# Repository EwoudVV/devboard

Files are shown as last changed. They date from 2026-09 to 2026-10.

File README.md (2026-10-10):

# Devboard

A small STM32 devboard for deving

## details
- Compatible with a breadboard
- USB-C programming port
- SD card holder
- 32 header pins total: 22 GPIO, including 9 analog inputs, plus debug and power pins
- STM32 MCU
- 4 layer board
- 24x44mm board size
- 2 side component assembly

## images
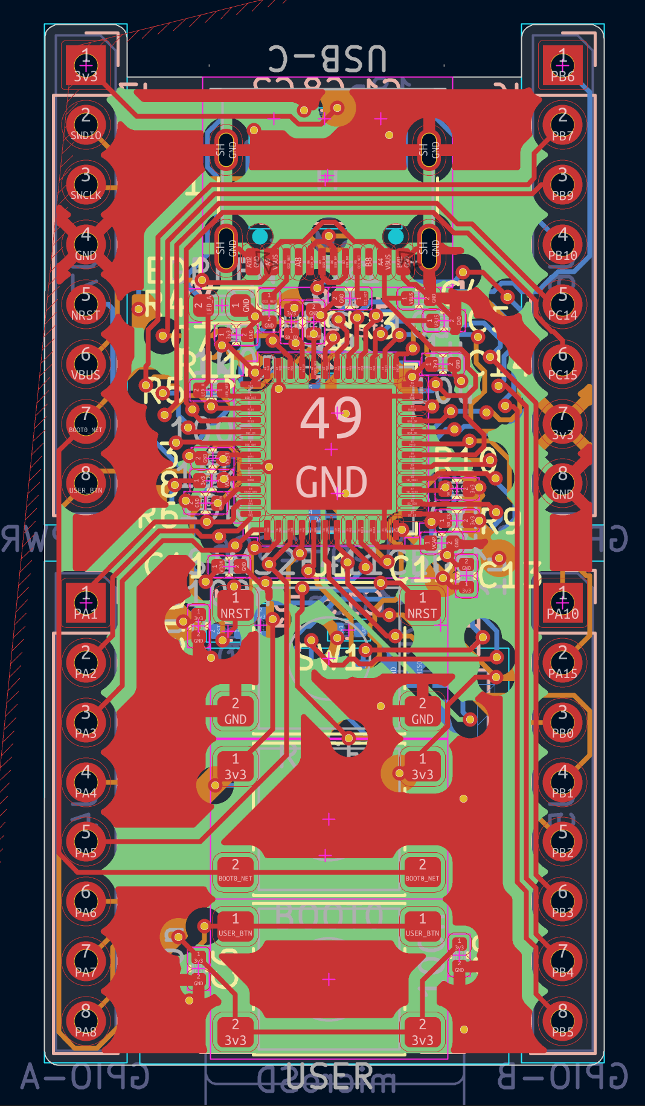
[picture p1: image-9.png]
The board in PCB editor: 
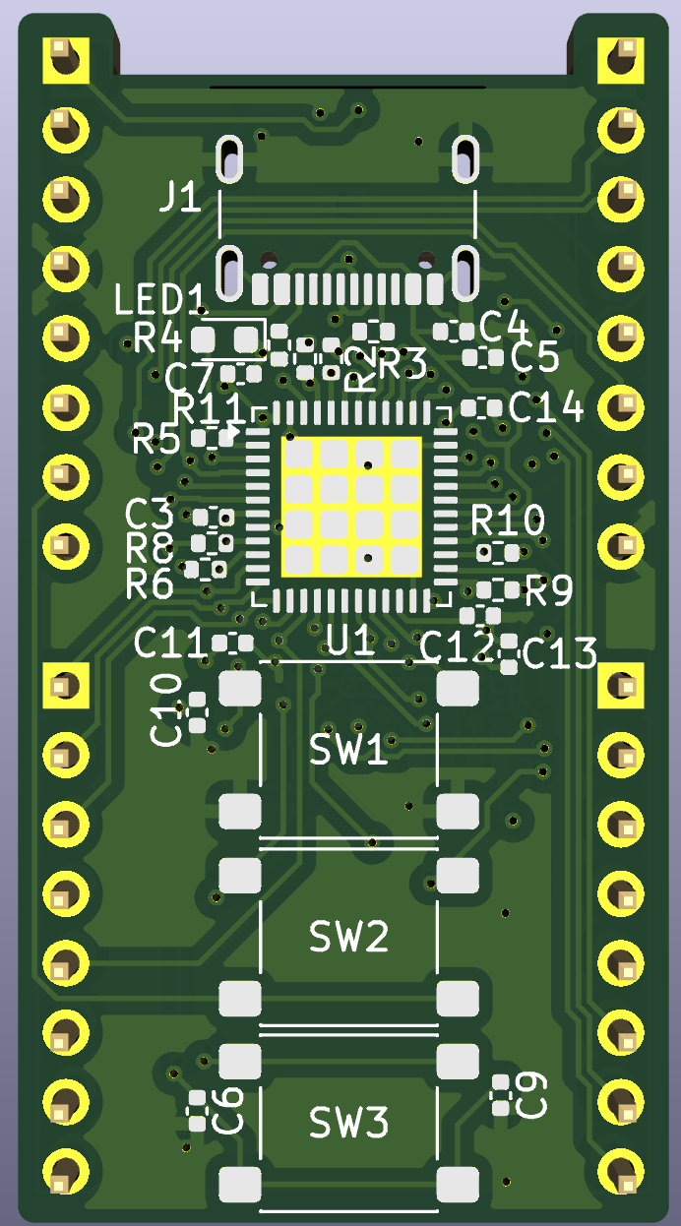
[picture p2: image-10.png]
The board in 3d viewer: 

## goal
- Purpose: a functional and useful devboard
- MCU: STM32 (MCU_ST_STM32F4:STM32F411CEUx)
- Features: USB-C + UART, SD card, expanded GPIO
- Size: as small as possible

## status

project finished!!
Once I get funding, I will order 10 assembled PCBs from PCBway.

## bom

Parts from the [PCBWay BOM](production/pcbway_bom.xlsx), with quantities for one board. The [KiCad CSV export](production/bom.csv) is also available.

| Reference | Qty | Manufacturer | Part number | Package |
| --- | ---: | --- | --- | --- |
| C1, C2 | 2 | Murata | GRM1555C1H180JA01D | 0402 |
| C3, C6, C7, C8, C9, C11, C15 | 7 | Samsung | CL05B104KB5NNNC | 0402 |
| C5, C13 | 2 | Samsung | CL05A105KO5NNNC | 0402 |
| C4, C14 | 2 | Samsung | CL05A106KP5NNNC | 0402 |
| C10 | 1 | Murata | GRM155R61A475MEAA | 0402 |
| C12 | 1 | Murata | GRM155R61A225KE95D | 0402 |
| R3, R4 | 2 | Yageo | RC0402FR-075K1L | 0402 |
| R9, R10, R11, R12, R13 | 5 | Yageo | RC0402FR-0747KL | 0402 |
| R8 | 1 | Yageo | RC0402FR-0710RL | 0402 |
| R1, R2, R6 | 3 | Yageo | RC0402FR-0710KL | 0402 |
| R5 | 1 | Yageo | RC0402FR-071KL | 0402 |
| U1 | 1 | STMicroelectronics | STM32F411CEU6 | QFN-48 7x7 |
| U2 | 1 | Diodes Incorporated | AP2112K-3.3TRG1 | SOT-23-5 |
| D1 | 1 | STMicroelectronics | USBLC6-2SC6 | SOT-23-6 |
| LED1 | 1 | Lite-On | LTST-C190GKT | 0603 |
| Y1 | 1 | Abracon | ABM3-25.000MHZ-D2Y-T | 5.0x3.2mm |
| J1 | 1 | GCT | USB4105-GF-A | USB-C 16P |
| J2 | 1 | Hirose | DM3AT-SF-PEJM5 | microSD |
| SW1, SW2, SW3 | 3 | C&K | PTS645SM43SMTR92 LFS | 6x6mm SMD |

The four through-hole headers are soldered separately and are not included in this BOM. For J1, check the USB4105 pin-length variant against the footprint, as noted in the PCBWay BOM.

## repo structure
- `devboard.kicad_pro` / `.kicad_sch` / `.kicad_pcb`: KiCad project (root)
- `journal.md`: devlog journals
- `README.md`: this file
- `production`: production files, like gerbers, bom, cpl
- `docs/pinout.md`: header pinout and on-board connections
- `firmware`: starter LED, button, and USB serial firmware

## getting started

[Pinout and connections](docs/pinout.md)

[Building and flashing the starter firmware](firmware/README.md)

Designed by EVV
Made for Hack Club Half Life
9/16/26

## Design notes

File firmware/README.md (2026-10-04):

# Starter firmware

Blinks the green LED on PC13, reports the USER button on PA0, and gives the board a USB serial port. The SD card pins are left alone.

Compiled for STM32F411CEU6 with 512 KB flash and 128 KB RAM. It uses the board's 25 MHz crystal to run the CPU at 96 MHz and USB at 48 MHz. The button is active high and debounced for 25 ms. The LED is active high and changes state every 500 ms.

This builds, but I haven't tested it on a physical board yet.

## Build

Install a complete [Arm GNU embedded toolchain](https://developer.arm.com/tools-and-software/gnu-toolchain), including its C library. A compiler-only package without `stdint.h`, `nano.specs`, and the embedded libraries is not enough.

From this folder:

```sh
sh setup.sh
make
make test
```

If the toolchain is not on PATH:

```sh
make PREFIX=/path/to/toolchain/bin/arm-none-eabi-
```

Outputs are `build/devboard.elf`, `build/devboard.bin`, and `build/devboard.hex`. The BIN and HEX from the checked build are also in `releases/`.

`setup.sh` downloads libopencm3 from its upstream repository and checks out the revision in `libopencm3.version`. The library is LGPL-3.0-or-later; its license is included in `LIBRARY-LICENSE.txt`. The local download and build folders are ignored by Git.

## Flash over SWD

Power the board through USB-C. Connect the probe's ground to J7.4, SWDIO to J7.2, and SWCLK to J7.3. If the probe has a target voltage sense input, connect it to J7.1. NRST is available on J7.5. Check your probe's pin labels before connecting it.

With an ST-Link and OpenOCD installed:

```sh
make flash
```

The command programs the ELF, verifies it, and resets the board. It does not require a separately installed bootloader. For this application, release BOOT0 before resetting.

## USB serial

Use a USB data cable. After flashing and resetting, open the new USB serial device at 115200 baud. On macOS it should appear as `/dev/cu.usbmodem*`; Linux normally uses `/dev/ttyACM*`. The baud value is accepted for terminal compatibility; USB carries the data directly.

The terminal should show:

```text
devboard ready
Type help for commands.
```

Send a command followed by Enter:

| Command | Result |
| --- | --- |
| `help` | Lists the commands |
| `status` | Uptime, button state, press count, LED state, blink mode, and dropped-message count |
| `led on` | Stops blinking and turns the LED on |
| `led off` | Stops blinking and turns the LED off |
| `blink` | Resumes blinking |

Pressing USER prints `button pressed`; releasing it prints `button released`. RESET restarts the application and may reconnect the serial port. The terminal needs to assert DTR, which normal serial terminals do when opening the port.

USB output is buffered without waiting for a host. The LED and button keep running when the terminal is closed. If a connected host stops reading long enough to fill the buffer, the message is dropped rather than blocking the application; `status` includes the drop count.

The USB descriptor uses the development CDC identifiers `0483:5740`. Use assigned identifiers for a distributed product. The serial string is currently `DEVBOARD-001`, for the first test board.

## First board checks

1. Before connecting USB, check for a short between 3.3 V and GND.
2. Power it and measure the 3.3 V rail.
3. Flash over SWD and verify that PC13's LED blinks.
4. Open USB serial, send `status`, and try the LED commands.
5. Press and release USER. Confirm one event per action and a rising press count.
6. Reset, then disconnect and reconnect USB. Check that serial comes back and the LED still runs.

The host test checks button bounce, a held press, release, and the millisecond counter wrapping. It does not test USB enumeration or physical hardware.

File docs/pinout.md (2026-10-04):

# Devboard pinout

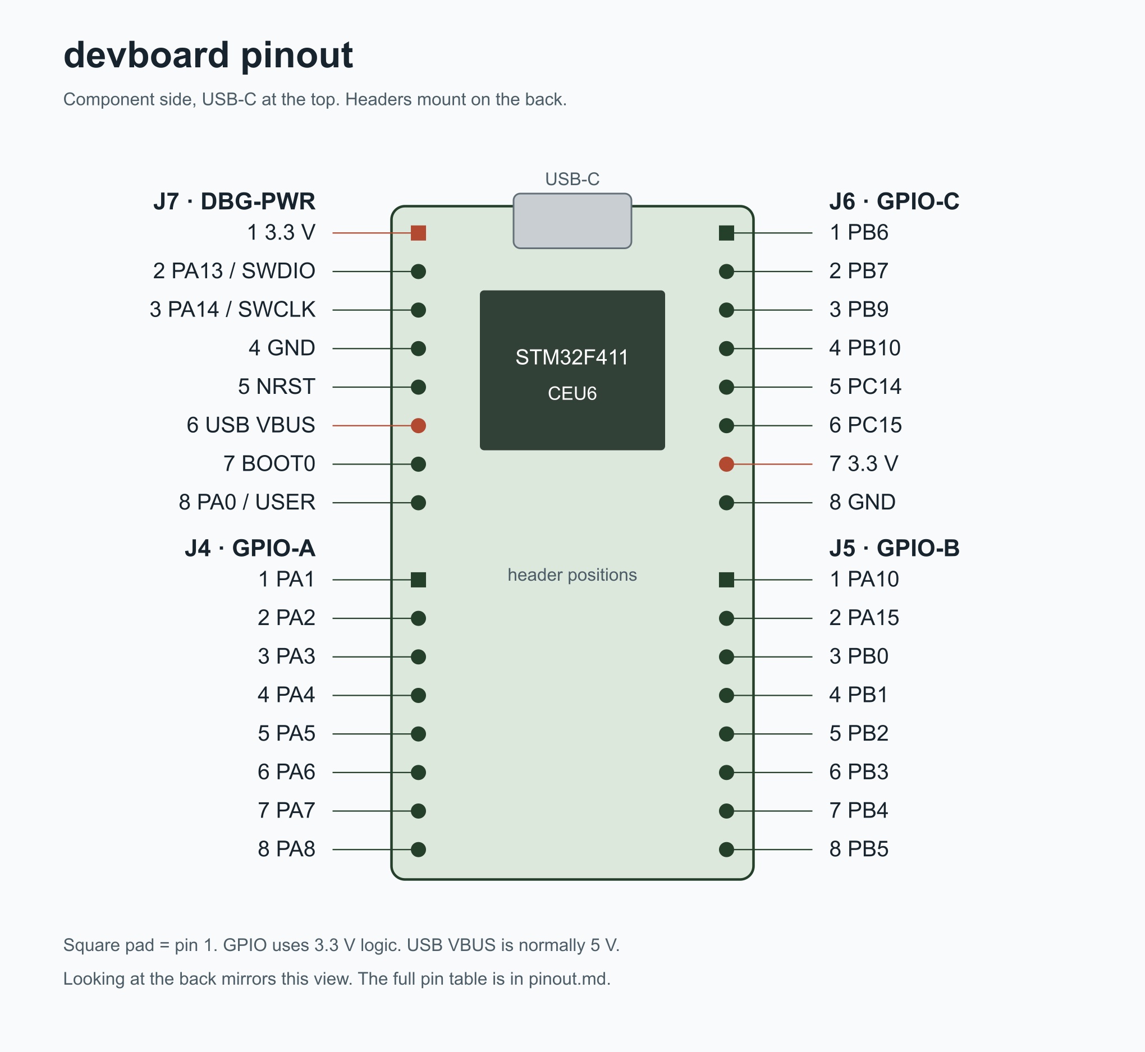
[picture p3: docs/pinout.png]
Devboard pinout


View from the component side, with USB-C at the top. The headers are mounted on the back. Pin 1 is the square pad. Looking at the back mirrors the positions in this diagram.

The four headers have 32 pins total. J4, J5, and J6 expose 22 GPIO pins, including nine ADC inputs. J7 carries power, programming, reset, boot, and the user button.

| Pin | J7: upper left | J6: upper right | J4: lower left | J5: lower right |
| --- | --- | --- | --- | --- |
| 1 | 3.3 V | PB6 | PA1 / ADC1_IN1 | PA10 |
| 2 | PA13 / SWDIO | PB7 | PA2 / ADC1_IN2 | PA15 |
| 3 | PA14 / SWCLK | PB9 | PA3 / ADC1_IN3 | PB0 / ADC1_IN8 |
| 4 | GND | PB10 | PA4 / ADC1_IN4 | PB1 / ADC1_IN9 |
| 5 | NRST | PC14 | PA5 / ADC1_IN5 | PB2 |
| 6 | USB VBUS | PC15 | PA6 / ADC1_IN6 | PB3 |
| 7 | BOOT0 | 3.3 V | PA7 / ADC1_IN7 | PB4 |
| 8 | PA0 / USER | GND | PA8 | PB5 |

GPIO and ADC signals use 3.3 V logic. Keep analog inputs between GND and 3.3 V. USB VBUS is the USB supply, normally 5 V; it is not a GPIO pin. Power the first board from USB-C rather than driving the 3.3 V rail from another supply.

## On-board connections

| Function | MCU pin | Notes |
| --- | --- | --- |
| Green LED | PC13 | Active high, through R5 (1 kΩ) to the LED; LED cathode goes to GND |
| USER button | PA0 | Active high, external 10 kΩ pulldown; also on J7.8 |
| RESET button | NRST | Pulls reset low; also on J7.5 |
| BOOT0 button | BOOT0 | Pulls BOOT0 high; also on J7.7 |
| USB D− | PA11 | USB OTG FS, AF10 |
| USB D+ | PA12 | USB OTG FS, AF10 |
| USB VBUS sense | PA9 | Connected to USB VBUS |
| SWD data | PA13 | J7.2 |
| SWD clock | PA14 | J7.3 |
| Main crystal | PH0 / PH1 | 25 MHz |
| SD chip select | PB12 | Active low |
| SD clock | PB13 | SPI2, AF5 |
| SD MISO | PB14 | SPI2, AF5 |
| SD MOSI | PB15 | SPI2, AF5 |
| SD card detect | PB8 | Pulled up; check the socket switch behavior on the first board |

The SD slot is wired for SPI, not four-bit SDIO. Its DAT1 and DAT2 pins have pullups but are not connected to MCU data pins. PA0 and PC13 are occupied by the button and LED. PA9, PA11, and PA12 are occupied by USB. Keep PA13 and PA14 for SWD while debugging.

PA15, PB3, and PB4 have debug alternate functions after reset. If you use them as GPIO, configure them explicitly and keep SWD on PA13/PA14. PC14 and PC15 are low-speed oscillator pins that can be GPIO while the LSE oscillator is disabled.

Pin assignments were checked against both the schematic netlist and PCB pads. MCU alternate functions and ADC channels are listed in the [STM32F411 datasheet](https://www.st.com/resource/en/datasheet/stm32f411cc.pdf).

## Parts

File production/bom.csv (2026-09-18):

Refs | Value | Footprint | Qty | DNP
C1 | 18p | Capacitor_SMD:C_0402_1005Metric | 1
C2 | 18p | Capacitor_SMD:C_0402_1005Metric | 1
C3 | 100n | Capacitor_SMD:C_0402_1005Metric | 1
C4 | 10u | Capacitor_SMD:C_0402_1005Metric | 1
C5 | 1u | Capacitor_SMD:C_0402_1005Metric | 1
C6 | 100n | Capacitor_SMD:C_0402_1005Metric | 1
C7 | 100n | Capacitor_SMD:C_0402_1005Metric | 1
C8 | 100n | Capacitor_SMD:C_0402_1005Metric | 1
C9 | 100n | Capacitor_SMD:C_0402_1005Metric | 1
C10 | 4u7 | Capacitor_SMD:C_0402_1005Metric | 1
C11 | 100n | Capacitor_SMD:C_0402_1005Metric | 1
C12 | 2u2 | Capacitor_SMD:C_0402_1005Metric | 1
C13 | 1u | Capacitor_SMD:C_0402_1005Metric | 1
C14 | 10u | Capacitor_SMD:C_0402_1005Metric | 1
C15 | 100n | Capacitor_SMD:C_0402_1005Metric | 1
D1 | USBLC6-2SC6 | Package_TO_SOT_SMD:SOT-23-6 | 1
J1 | USB-C | Connector_USB:USB_C_Receptacle_GCT_USB4105-xx-A_16P_TopMnt_Horizontal | 1
J2 | microSD | Connector_Card:microSD_HC_Hirose_DM3AT-SF-PEJM5 | 1
LED1 | GREEN | LED_SMD:LED_0603_1608Metric | 1
P1 | PWR_FLAG |  | 1
P2 | PWR_FLAG |  | 1
P3 | PWR_FLAG |  | 1
R1 | 10k | Resistor_SMD:R_0402_1005Metric | 1
R2 | 10k | Resistor_SMD:R_0402_1005Metric | 1
R3 | 5k1 | Resistor_SMD:R_0402_1005Metric | 1
R4 | 5k1 | Resistor_SMD:R_0402_1005Metric | 1
R5 | 1k | Resistor_SMD:R_0402_1005Metric | 1
R6 | 10k | Resistor_SMD:R_0402_1005Metric | 1
R8 | 10R | Resistor_SMD:R_0402_1005Metric | 1
R9 | 47k | Resistor_SMD:R_0402_1005Metric | 1
R10 | 47k | Resistor_SMD:R_0402_1005Metric | 1
R11 | 47k | Resistor_SMD:R_0402_1005Metric | 1
R12 | 47k | Resistor_SMD:R_0402_1005Metric | 1
R13 | 47k | Resistor_SMD:R_0402_1005Metric | 1
SW1 | RESET | Button_Switch_SMD:SW_SPST_PTS645Sx43SMTR92 | 1
SW2 | BOOT0 | Button_Switch_SMD:SW_SPST_PTS645Sx43SMTR92 | 1
SW3 | USER | Button_Switch_SMD:SW_SPST_PTS645Sx43SMTR92 | 1
U1 | STM32F411CEU6 | Package_DFN_QFN:QFN-48-1EP_7x7mm_P0.5mm_EP5.15x5.15mm | 1
U2 | AP2112K-3.3 | Package_TO_SOT_SMD:SOT-23-5 | 1
Y1 | 25MHz | Crystal:Crystal_SMD_Abracon_ABM3-2Pin_5.0x3.2mm | 1

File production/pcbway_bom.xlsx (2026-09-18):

Item # | Designator | Qty | Manufacturer | Mfg Part # | Description | Package | Type
1 | C1,C2 | 2 | Murata | GRM1555C1H180JA01D | CAP CER 18PF 50V C0G 0402 | 0402 | SMD
2 | C3,C6,C7,C8,C9,C11,C15 | 7 | Samsung | CL05B104KB5NNNC | CAP CER 100NF 50V X7R 0402 | 0402 | SMD
3 | C5,C13 | 2 | Samsung | CL05A105KO5NNNC | CAP CER 1UF 16V X5R 0402 | 0402 | SMD
4 | C4,C14 | 2 | Samsung | CL05A106KP5NNNC | CAP CER 10UF 10V X5R 0402 | 0402 | SMD
5 | C10 | 1 | Murata | GRM155R61A475MEAA | CAP CER 4.7UF 10V X5R 0402 | 0402 | SMD
6 | C12 | 1 | Murata | GRM155R61A225KE95D | CAP CER 2.2UF 10V X5R 0402 | 0402 | SMD
7 | R3,R4 | 2 | Yageo | RC0402FR-075K1L | RES 5.1K 1% 1/16W 0402 | 0402 | SMD
8 | R9,R10,R11,R12,R13 | 5 | Yageo | RC0402FR-0747KL | RES 47K 1% 1/16W 0402 | 0402 | SMD
9 | R8 | 1 | Yageo | RC0402FR-0710RL | RES 10R 1% 1/16W 0402 | 0402 | SMD
10 | R1,R2,R6 | 3 | Yageo | RC0402FR-0710KL | RES 10K 1% 1/16W 0402 | 0402 | SMD
11 | R5 | 1 | Yageo | RC0402FR-071KL | RES 1K 1% 1/16W 0402 | 0402 | SMD
12 | U1 | 1 | STMicroelectronics | STM32F411CEU6 | MCU ARM CORTEX-M4 100MHZ 512KB UFQFPN48 | QFN-48 7x7 | SMD
13 | U2 | 1 | Diodes Incorporated | AP2112K-3.3TRG1 | LDO 3.3V 600MA SOT-23-5 | SOT-23-5 | SMD
14 | D1 | 1 | STMicroelectronics | USBLC6-2SC6 | ESD PROTECTION 2-LINE SOT-23-6 | SOT-23-6 | SMD
15 | LED1 | 1 | Lite-On | LTST-C190GKT | LED GREEN 0603 SMD | 0603 | SMD
16 | Y1 | 1 | Abracon | ABM3-25.000MHZ-D2Y-T | CRYSTAL 25MHZ 18PF 2-SMD 5.0x3.2 | 5.0x3.2mm | SMD
17 | J1 | 1 | GCT | USB4105-GF-A | USB-C RECEPTACLE 16P TOP-MOUNT SMD (VERIFY PIN-LENGTH VARIANT VS FOOTPRINT) | USB-C 16P | SMD
18 | J2 | 1 | Hirose | DM3AT-SF-PEJM5 | MICROSD PUSH-PULL SOCKET W/ CARD DETECT | microSD | SMD
19 | SW1,SW2,SW3 | 3 | C&K | PTS645SM43SMTR92 LFS | TACT SWITCH 6MM SMD GULLWING | 6x6mm SMD | SMD

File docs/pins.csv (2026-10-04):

Header | Pin | Net
J7 | 1 | 3v3
J7 | 2 | SWDIO
J7 | 3 | SWCLK
J7 | 4 | GND
J7 | 5 | NRST
J7 | 6 | VBUS
J7 | 7 | BOOT0_NET
J7 | 8 | USER_BTN
J6 | 1 | PB6
J6 | 2 | PB7
J6 | 3 | PB9
J6 | 4 | PB10
J6 | 5 | PC14
J6 | 6 | PC15
J6 | 7 | 3v3
J6 | 8 | GND
J4 | 1 | PA1
J4 | 2 | PA2
J4 | 3 | PA3
J4 | 4 | PA4
J4 | 5 | PA5
J4 | 6 | PA6
J4 | 7 | PA7
J4 | 8 | PA8
J5 | 1 | PA10
J5 | 2 | PA15
J5 | 3 | PB0
J5 | 4 | PB1
J5 | 5 | PB2
J5 | 6 | PB3
J5 | 7 | PB4
J5 | 8 | PB5

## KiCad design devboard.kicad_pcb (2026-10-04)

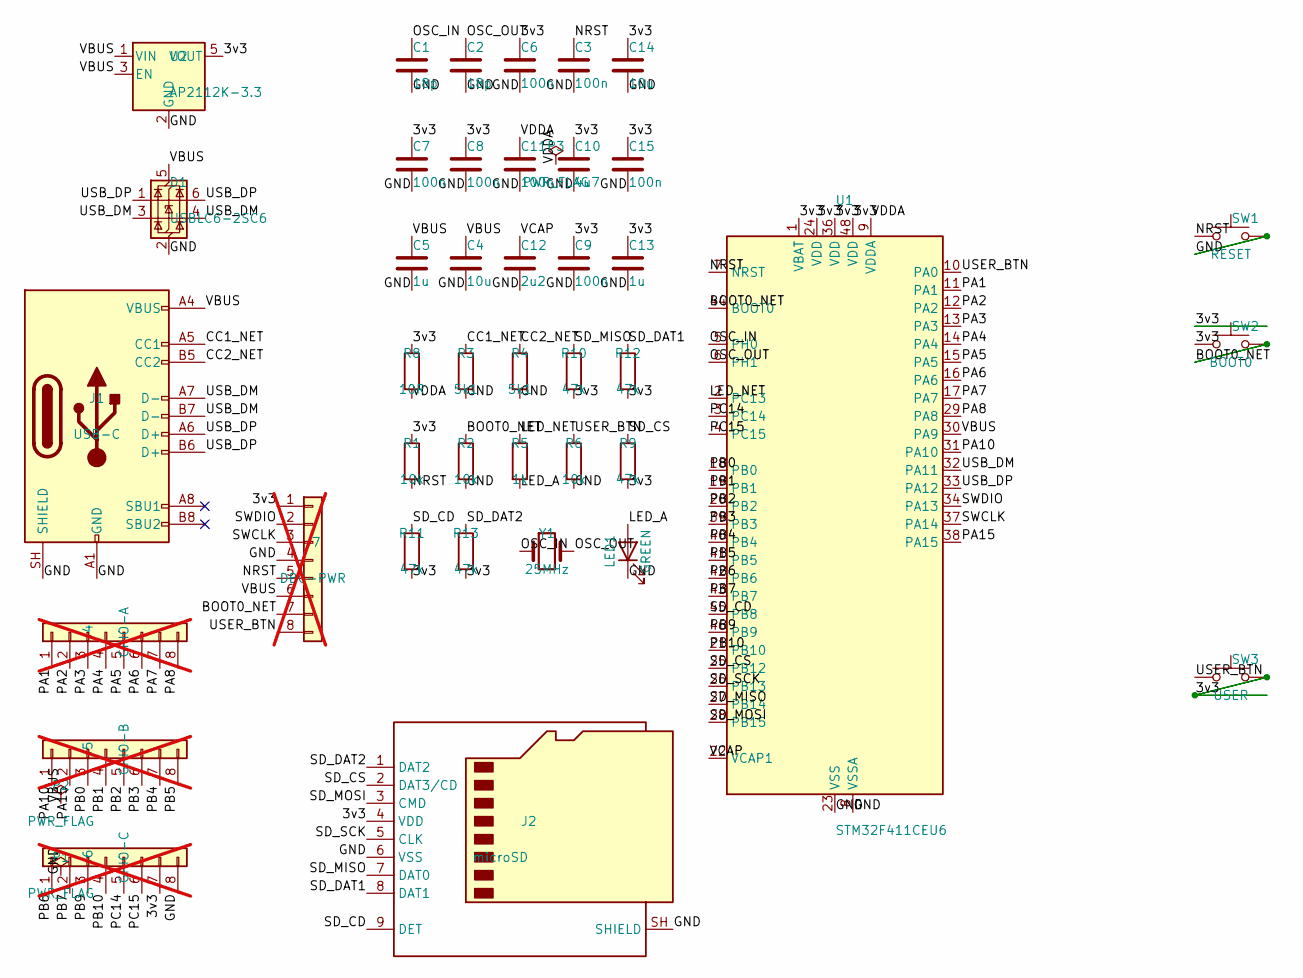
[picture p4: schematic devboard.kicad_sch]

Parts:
C1, C2: 18p; C_0402_1005Metric
C3, C6, C7, C8, C9, C11, C15: 100n; C_0402_1005Metric
C4, C14: 10u; C_0402_1005Metric
C5, C13: 1u; C_0402_1005Metric
C10: 4u7; C_0402_1005Metric
C12: 2u2; C_0402_1005Metric
D1: USBLC6-2SC6; SOT-23-6
J1: USB-C; USB_C_Receptacle_GCT_USB4105-xx-A_16P_TopMnt_Horizontal
J2: microSD; microSD_HC_Hirose_DM3AT-SF-PEJM5
J4: GPIO-A; PinHeader_1x08_P2.54mm_Vertical; not fitted
J5: GPIO-B; PinHeader_1x08_P2.54mm_Vertical; not fitted
J6: GPIO-C; PinHeader_1x08_P2.54mm_Vertical; not fitted
J7: DBG-PWR; PinHeader_1x08_P2.54mm_Vertical; not fitted
LED1: GREEN; LED_0603_1608Metric
P1, P2, P3: PWR_FLAG
R1, R2, R6: 10k; R_0402_1005Metric
R3, R4: 5k1; R_0402_1005Metric
R5: 1k; R_0402_1005Metric
R8: 10R; R_0402_1005Metric
R9, R10, R11, R12, R13: 47k; R_0402_1005Metric
SW1: RESET; SW_SPST_PTS645Sx43SMTR92
SW2: BOOT0; SW_SPST_PTS645Sx43SMTR92
SW3: USER; SW_SPST_PTS645Sx43SMTR92
U1: STM32F411CEU6; QFN-48-1EP_7x7mm_P0.5mm_EP5.15x5.15mm
U2: AP2112K-3.3; SOT-23-5
Y1: 25MHz; Crystal_SMD_Abracon_ABM3-2Pin_5.0x3.2mm

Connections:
3v3: C6.1, C7.1, C8.1, C9.1, C10.1, C13.1, C14.1, C15.1, J2.4 (VDD), J6.7, J7.1, R1.1, R8.1, R9.2, R10.2, R11.2, R12.2, R13.2, SW2.1, SW3.2, U1.1 (VBAT), U1.24 (VDD), U1.36 (VDD), U1.48 (VDD), U2.5 (VOUT)
BOOT0_NET: J7.7, R2.1, SW2.2, U1.44 (BOOT0)
CC1_NET: J1.A5 (CC1), R3.1
CC2_NET: J1.B5 (CC2), R4.1
GND: C1.2, C2.2, C3.2, C4.2, C5.2, C6.2, C7.2, C8.2, C9.2, C10.2, C11.2, C12.2, C13.2, C14.2, C15.2, D1.2 (GND), J1.A1 (GND), J1.A12 (GND), J1.B1 (GND), J1.B12 (GND), J1.SH (SHIELD), J2.6 (VSS), J2.SH (SHIELD), J6.8, J7.4, LED1.1 (K), P1.1, R2.2, R3.2, R4.2, R6.2, SW1.2, U1.8 (VSSA), U1.23 (VSS), U1.35 (VSS), U1.47 (VSS), U1.49 (VSS), U2.2 (GND)
LED_A: LED1.2 (A), R5.2
LED_NET: R5.1, U1.2 (PC13)
NRST: C3.1, J7.5, R1.2, SW1.1, U1.7 (NRST)
OSC_IN: C1.1, U1.5 (PH0), Y1.1
OSC_OUT: C2.1, U1.6 (PH1), Y1.2
PA1: J4.1, U1.11 (PA1)
PA2: J4.2, U1.12 (PA2)
PA3: J4.3, U1.13 (PA3)
PA4: J4.4, U1.14 (PA4)
PA5: J4.5, U1.15 (PA5)
PA6: J4.6, U1.16 (PA6)
PA7: J4.7, U1.17 (PA7)
PA8: J4.8, U1.29 (PA8)
PA10: J5.1, U1.31 (PA10)
PA15: J5.2, U1.38 (PA15)
PB0: J5.3, U1.18 (PB0)
PB1: J5.4, U1.19 (PB1)
PB2: J5.5, U1.20 (PB2)
PB3: J5.6, U1.39 (PB3)
PB4: J5.7, U1.40 (PB4)
PB5: J5.8, U1.41 (PB5)
PB6: J6.1, U1.42 (PB6)
PB7: J6.2, U1.43 (PB7)
PB9: J6.3, U1.46 (PB9)
PB10: J6.4, U1.21 (PB10)
PC14: J6.5, U1.3 (PC14)
PC15: J6.6, U1.4 (PC15)
SD_CD: J2.9 (DET), R11.1, U1.45 (PB8)
SD_CS: J2.2 (DAT3/CD), R9.1, U1.25 (PB12)
SD_DAT1: J2.8 (DAT1), R12.1
SD_DAT2: J2.1 (DAT2), R13.1
SD_MISO: J2.7 (DAT0), R10.1, U1.27 (PB14)
SD_MOSI: J2.3 (CMD), U1.28 (PB15)
SD_SCK: J2.5 (CLK), U1.26 (PB13)
SWCLK: J7.3, U1.37 (PA14)
SWDIO: J7.2, U1.34 (PA13)
USB_DM: D1.3 (I/O2), D1.4 (I/O2), J1.A7 (D-), J1.B7 (D-), U1.32 (PA11)
USB_DP: D1.1 (I/O1), D1.6 (I/O1), J1.A6 (D+), J1.B6 (D+), U1.33 (PA12)
USER_BTN: J7.8, R6.1, SW3.1, U1.10 (PA0)
VBUS: C4.1, C5.1, D1.5 (VBUS), J1.A4 (VBUS), J1.A9 (VBUS), J1.B4 (VBUS), J1.B9 (VBUS), J7.6, P2.1, U1.30 (PA9), U2.1 (VIN), U2.3 (EN)
VCAP: C12.1, U1.22 (VCAP1)
VDDA: C11.1, P3.1, R8.2, U1.9 (VDDA)

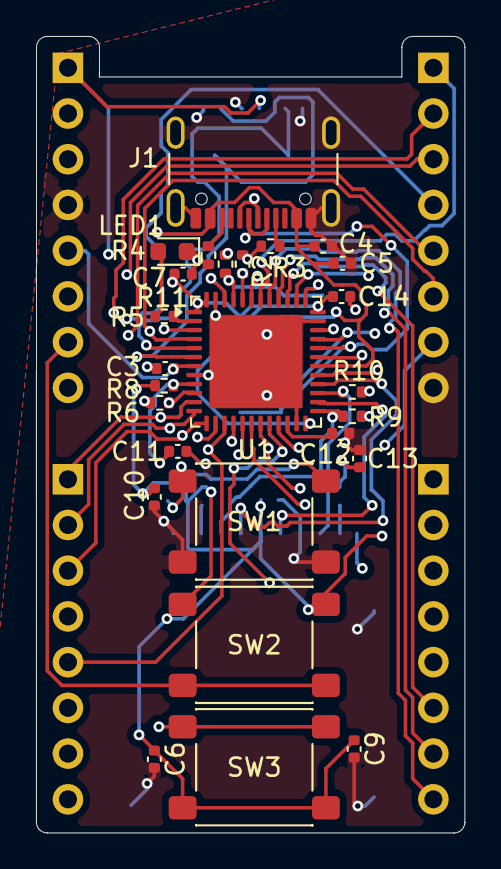
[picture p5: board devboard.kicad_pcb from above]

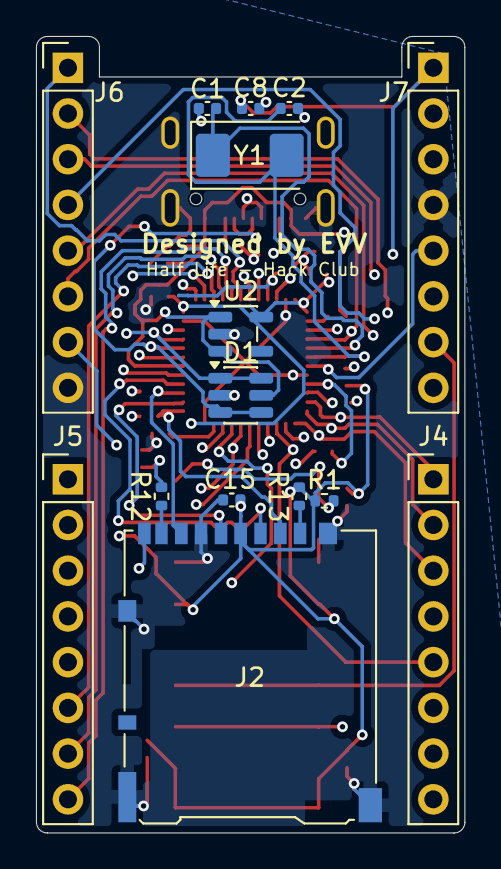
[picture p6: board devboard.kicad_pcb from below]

Board: 4 copper layers, 23.8 x 44.3 mm, 41 parts (15 on the bottom side), 47 nets.

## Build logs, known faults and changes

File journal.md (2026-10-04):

# Journal for my devboard
## Total time: 8 hours, 10 minutes

## Devlog 01: init and organizing repo and structure and KiCad project

Date: Sep 14
Time: 30 minutes

### what was done
- Created repo at `Documents/kicad/devboard` with `git init`
- Added `.gitignore` for KiCad + macOS
- Created structure: root KiCad project + `docs/devlog/`
- Created empty KiCad project `devboard` (`devboard.kicad_pro`, `devboard.kicad_sch`, `devboard.kicad_pcb`)
- Added and wrote `README.md`

### whats next
- decide MCU part + features + size target + layer stack

## Devlog 02:  decided the MCU and board spec.

Date: Sep 14
Time: 20 minutes

- MCU STM32F411CEU6 (UFQFPN48, 100MHz, USB FS, SDIO).
- USB-C native, no UART bridge, SWD for debug.
- microSD on SDMMC 4-bit.
- 4-layer, headers, smallest practical with clean USB.
- Next: schematic blocks (power, USB, clock, SWD, SD, GPIO).

## Devlog 03: completed the schematic!

Date: Sep 14
Time: 1 hour 30 minutes

Lapse link: [lapse](https://lapse.hackclub.com/timelapse/VmLhmJkZRPre)

I made a connection list so I have something to refer to while i made the schematic (that's why the lapse showed i kept alt tabbing), made the schematic, and after that i had to fix some things like missing capacitor gnds, stray gnd near header, and power flags.

Built: STM32F411CEU6 core with decoupling, AP2112K-3.3 power from USB-C,
USB-C with CC resistors and ESD, 25MHz crystal, NRST/BOOT0/USER buttons,
green LED, SWD plus debug header, microSD, GPIO broken out to headers.

Decisions: AP2112K over smaller LDOs for SD current peaks. SD runs in SPI mode
because SDIO_CMD needs PD2, which this package does not have.

Check: ERC 0 errors, netlist verified pin by pin, 45 parts, 50 nets.

Open for layout: microSD socket part number, header pitch, button and
crystal packages, then footprints and placement.

## Devlog 04: PCB work

Date: Sep 14-15
Time: 5 hours

I spent half an hour assigning footprints to all the symbols in the schematic, and then put them on the PCB.

(used lapse for this) I then placed all the parts in roughly the right positions, and then started routing:
[lapse pt1](https://lapse.hackclub.com/timelapse/6VpJYj4qbbbp)
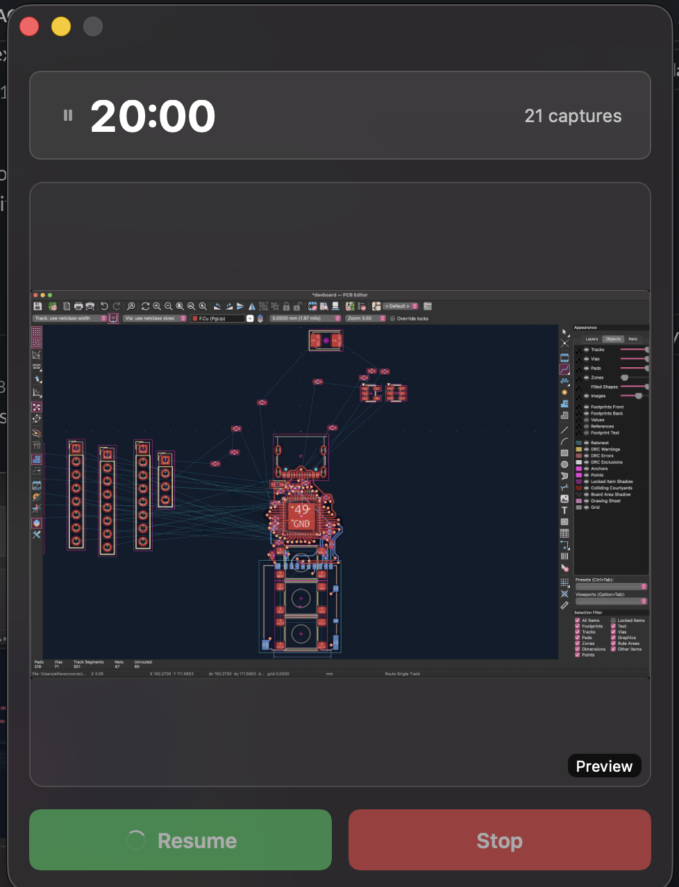
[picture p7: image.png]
lapse pt2
my lapse got stuck when i clicked the resume button so no link :( but i had 20 minutes here 
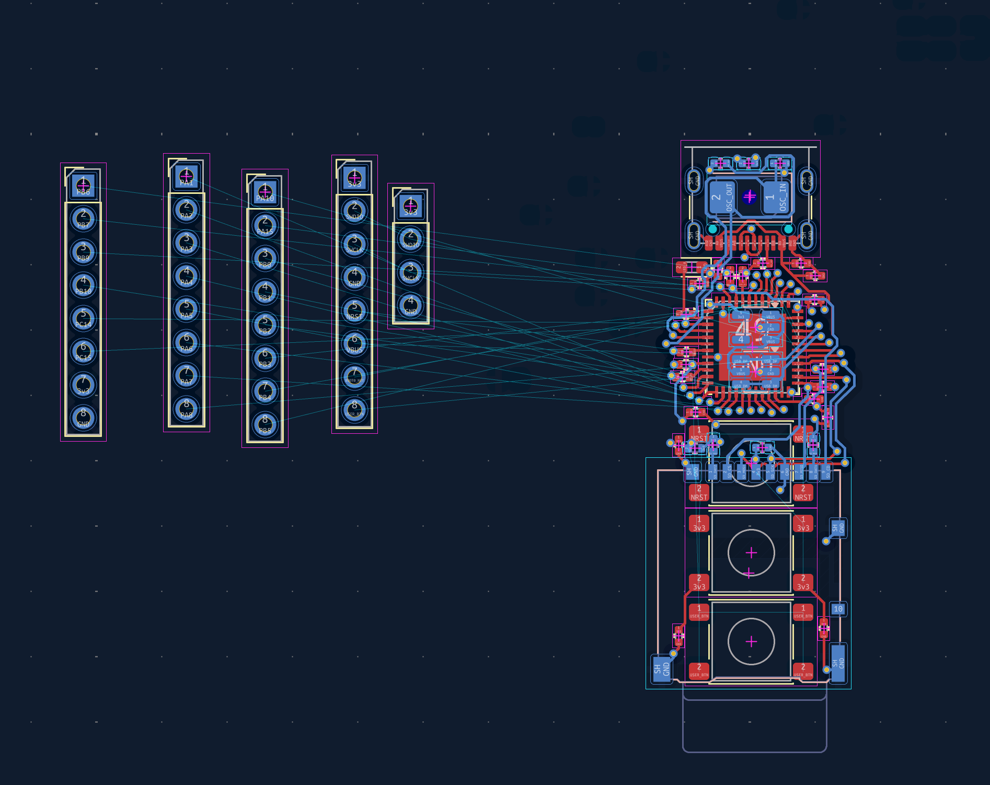
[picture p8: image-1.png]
Now ive finished the main routing, and all thats left to do is wire up the header pins. This is a 4 layer pcb, so the top and bottom layers are misc signals, the second layer is a ground plane, and I reserved the third layer for routing the header pins. I already have a fanout of vias at the mcu so it should be easy. I dont have a lapse link for this because i did this offline. 
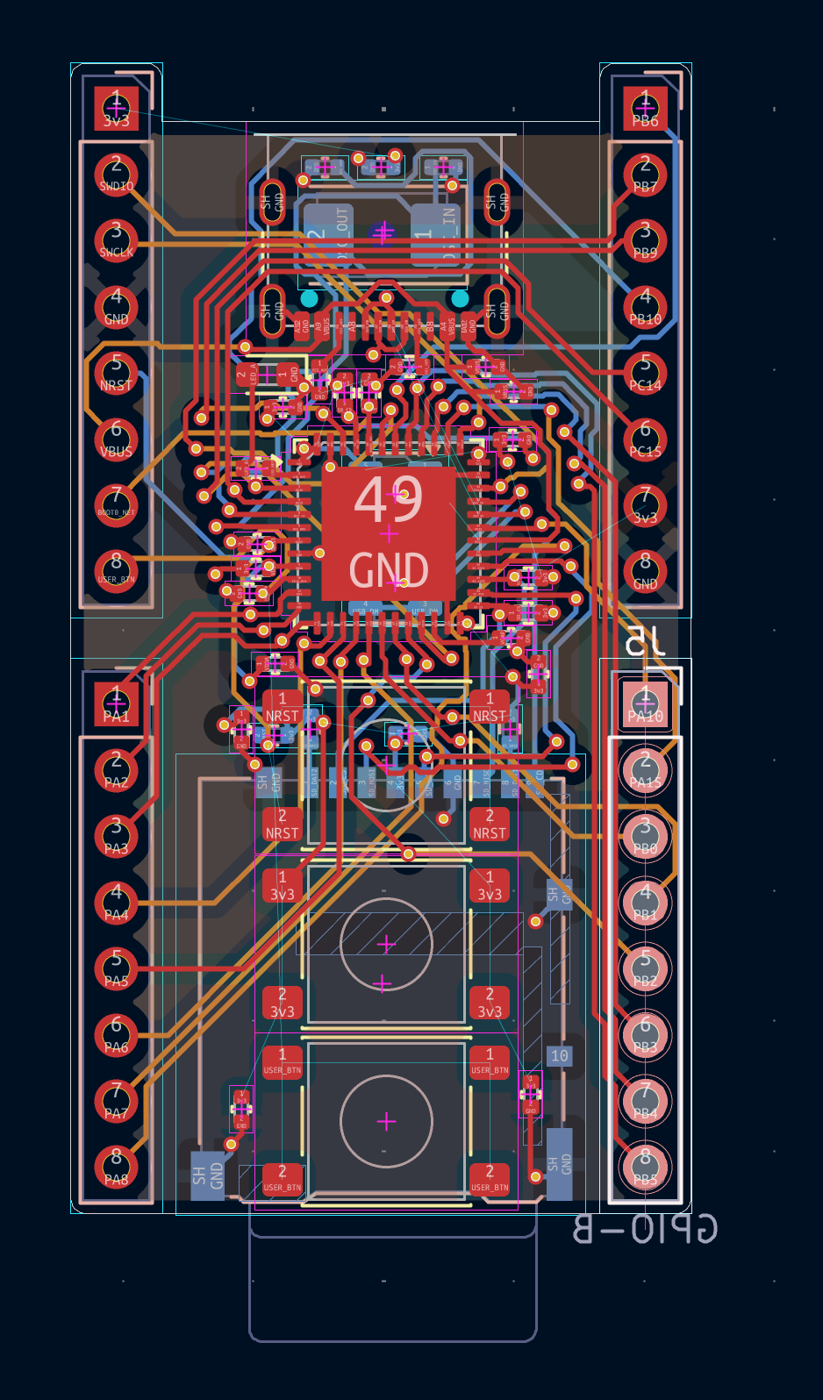
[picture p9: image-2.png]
routing
Finished the main routing: . Again, no lapse with this one, because i did this offline. Most stuff is routed, but the header pins were quite hard because there were many vias in the way. I also noticed something weird with the buttons: all pads of each button are the same net, so I will fix that. Also, during routing, I put a 3v3 plane AND ground plane on the same layer, so I will have to redo the 3v3 stuff. I also placed the pins in a place so that it's compatible with a breadboard!
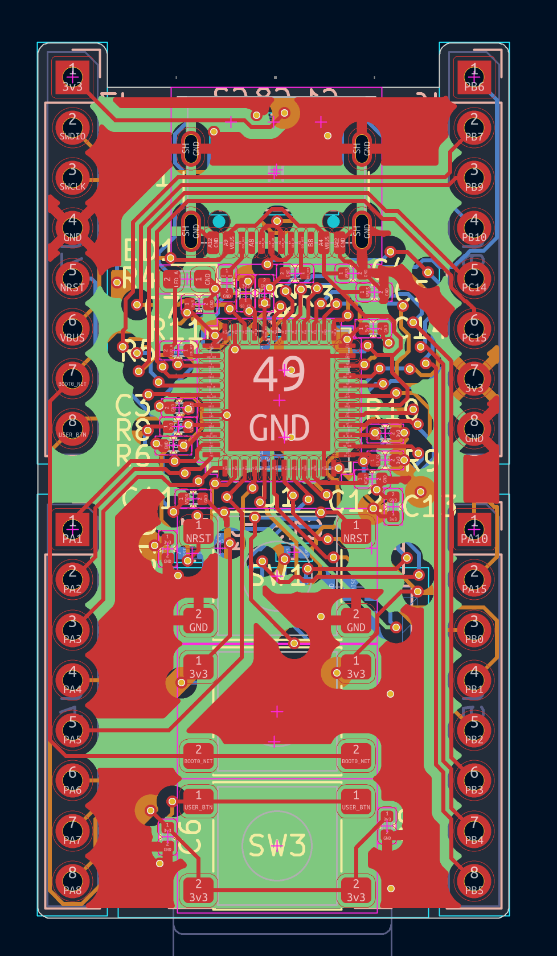
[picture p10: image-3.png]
f.cu
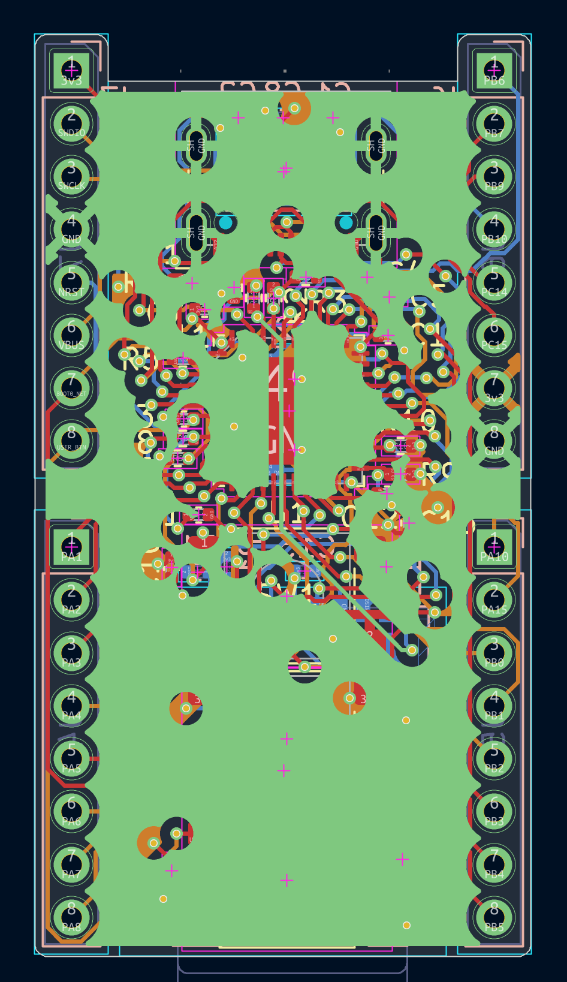
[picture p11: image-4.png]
in1.cu
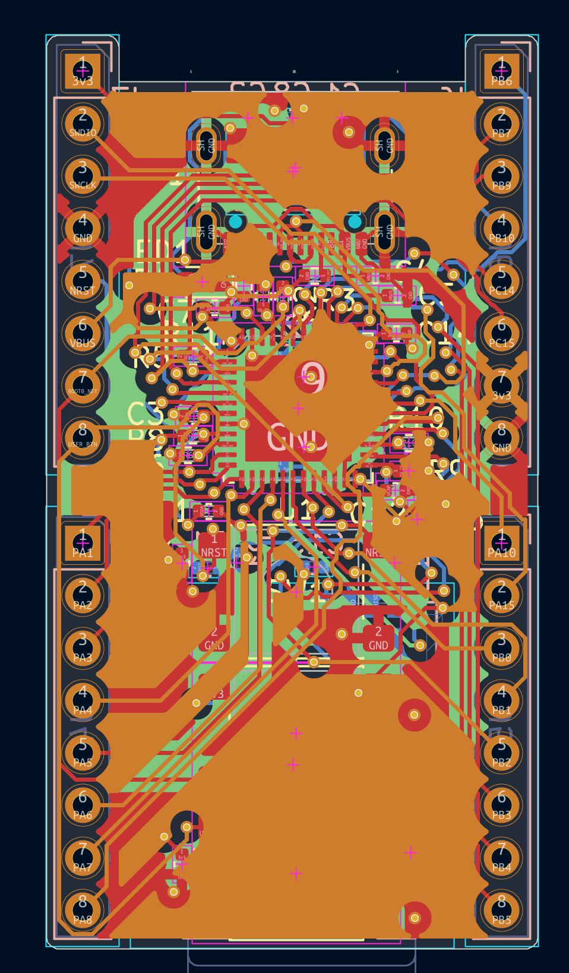
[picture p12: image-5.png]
in2.cu
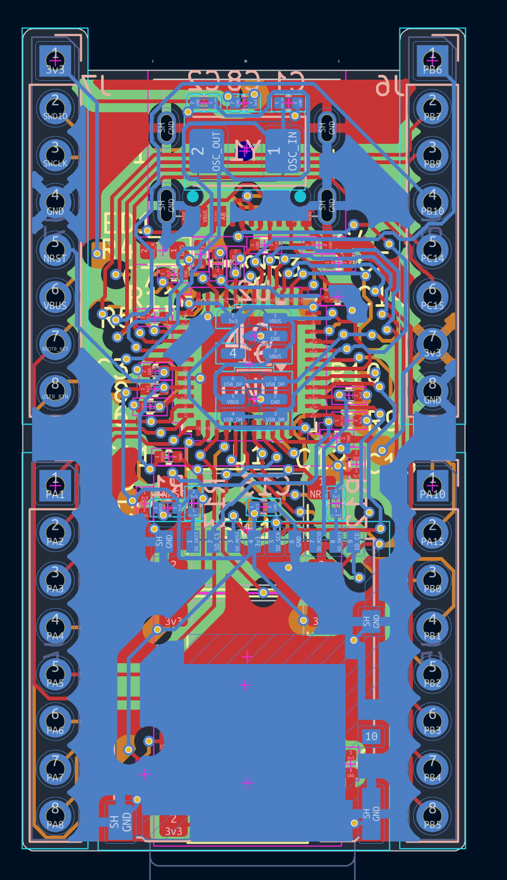
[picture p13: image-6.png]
b.cu
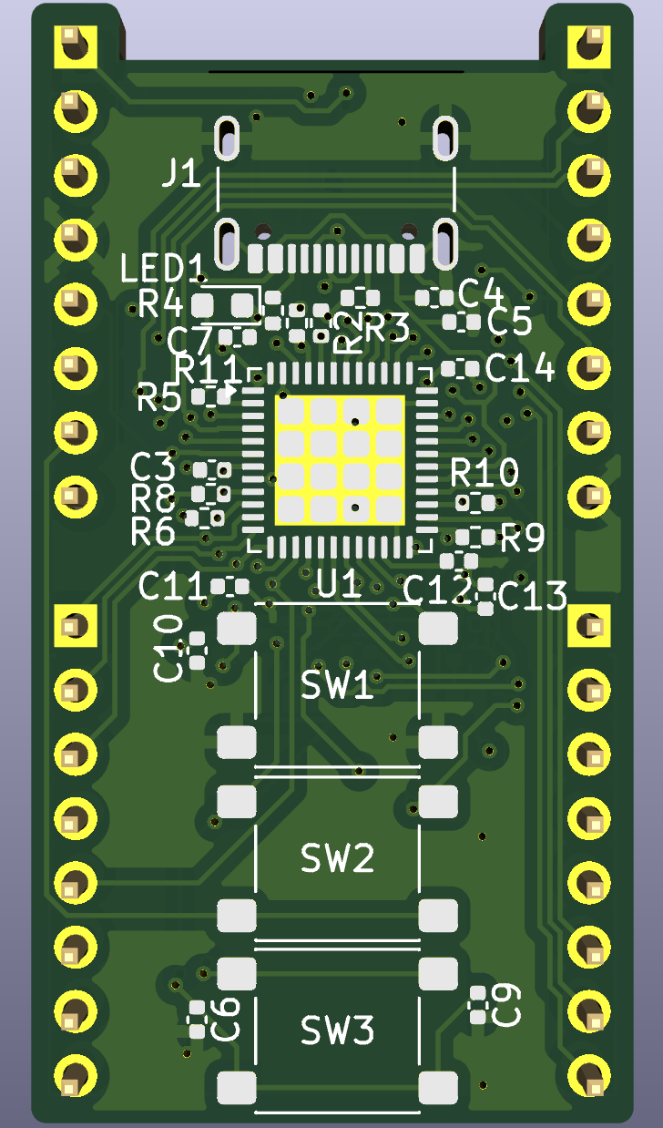
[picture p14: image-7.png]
front 3d
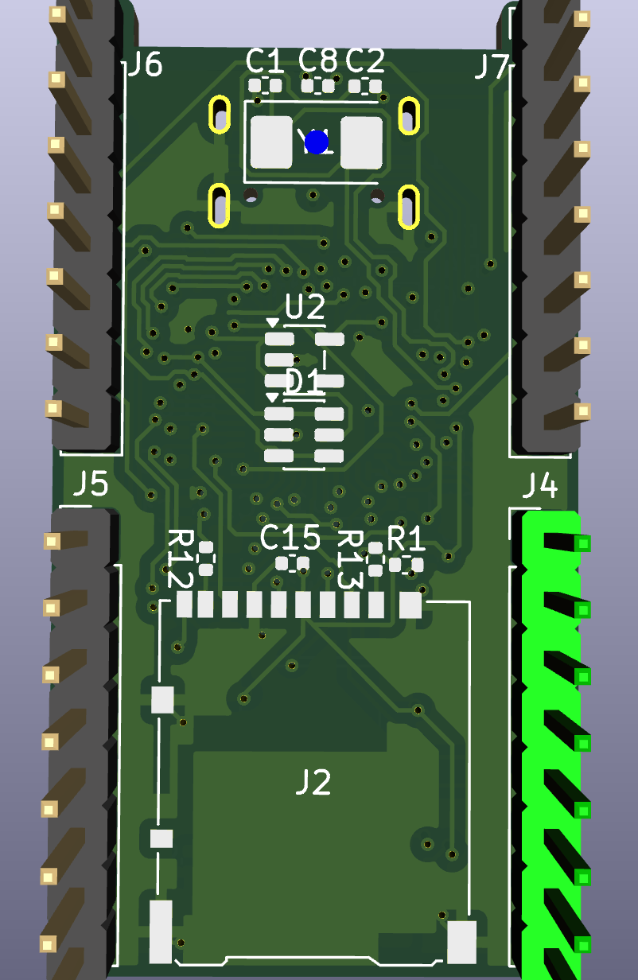
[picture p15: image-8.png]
back 3d
finished ALL routing! there were 23 more nets to route, did all of them. some pictures:      
during this time, i also cleared up some drc errors, mostly clearance violation stuff. theres still 8 things: 4hole clearance violations, which is out of my control because thats between one of the usb-c pads and the mounting hole for it, and also 4 of this thermal relief connection zone errors which i have no idea what they are, and will see what it is and fix now.
ok they ended up being fine to ignore

## Devlog 05: Fab outputs

Date: Sep 15
Time: 30 min

I made a production folder with the gerbers, bom, and cpl files. The bom took me a while to put together, i had to source all the right components.
I also found that C2 reads GND for some reason, so i fixed that.

## Devlog 06: polishing

Date: Sep 16
Time: 20 min

Added more details to the readme, including some images.

## Devlog 07: Production fix

Date: Sep 18
Time: 30 min

PCBway emailed me to confirm the order, and i noticed $25 for just the 4 tht headers. I have these headers and can easily solder them myself, so i said to remove them and also marked the headers as DNP in the prod files. There were also suggestions from them to replace 2 bulk decoupling capacitors with another one because it was out of stock, so i approved that.

## Devlog 08: pinout and firmware

Date: Oct 4
Time: 1 hour

made a pinout diagram for all 32 header pins and checked it against the schematic and PCB. also corrected the analog pin count in the readme. the SD card uses SPI, so i documented those pins separately.

added starter firmware for the blinking LED, user button, and USB serial. it has commands to turn the LED on and off, resume blinking, and show the button state and press count. it compiles, and the button debounce tests pass. i still need the physical board to test USB and the actual pins.

ran fresh ERC and DRC checks and fixed the incomplete ground thermals with direct connections on seven pads. there are now no active DRC errors or unrouted connections. the older excluded USB connector clearance findings and other warnings are still there. refreshed the gerbers and wrote flashing instructions.

### Devlog 09: got project ready for submission

Date: Oct 4
Time: 1.34 hours

got project ready for submission! i sourced exact links and did all the add to cart process stuff, made a simple video, etc. I made

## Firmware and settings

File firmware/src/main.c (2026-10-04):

#include <stdbool.h>
#include <stdint.h>
#include <string.h>
#include <libopencm3/cm3/systick.h>
#include <libopencm3/stm32/rcc.h>
#include <libopencm3/stm32/gpio.h>
#include "board.h"
#include "button.h"
#include "usb_serial.h"

static volatile uint32_t ticks;
static bool blink = true;
static bool led_on;
static struct button_state button;
static uint32_t presses;

void sys_tick_handler(void)
{
    ticks++;
}

static void led_set(bool on)
{
    led_on = on;
    if (on) gpio_set(LED_PORT, LED_PIN);
    else gpio_clear(LED_PORT, LED_PIN);
}

static char *append_text(char *out, const char *text)
{
    while (*text) *out++ = *text++;
    return out;
}

static char *append_number(char *out, uint32_t number)
{
    char digits[10];
    unsigned count = 0;
    do { digits[count++] = (char)('0' + number % 10u); number /= 10u; } while (number);
    while (count) *out++ = digits[--count];
    return out;
}

static void status(void)
{
    char text[160], *p = text;
    p = append_number(append_text(p, "uptime_ms="), ticks);
    p = append_number(append_text(p, " button="), button.pressed);
    p = append_number(append_text(p, " presses="), presses);
    p = append_number(append_text(p, " led="), led_on);
    p = append_text(append_text(p, " mode="), blink ? "blink" : "manual");
    p = append_number(append_text(p, " dropped="), usb_serial_dropped());
    p = append_text(p, "\r\n");
    *p = '\0';
    usb_serial_write(text);
}

static void command(const char *line)
{
    if (!strcmp(line, "led on")) { blink = false; led_set(true); }
    else if (!strcmp(line, "led off")) { blink = false; led_set(false); }
    else if (!strcmp(line, "blink")) blink = true;
    else if (!strcmp(line, "status")) { status(); return; }
    else if (!strcmp(line, "help")) {
        usb_serial_write("help | status | led on | led off | blink\r\n"); return;
    } else { usb_serial_write("Unknown command. Type help.\r\n"); return; }
    usb_serial_write("ok\r\n");
}

int main(void)
{
    rcc_clock_setup_pll(&rcc_hse_25mhz_3v3[RCC_CLOCK_3V3_96MHZ]);
    rcc_periph_clock_enable(RCC_GPIOA);
    rcc_periph_clock_enable(RCC_GPIOC);
    rcc_periph_clock_enable(RCC_OTGFS);
    gpio_clear(LED_PORT, LED_PIN);
    gpio_mode_setup(LED_PORT, GPIO_MODE_OUTPUT, GPIO_PUPD_NONE, LED_PIN);
    gpio_set_output_options(LED_PORT, GPIO_OTYPE_PP, GPIO_OSPEED_2MHZ, LED_PIN);
    gpio_mode_setup(BUTTON_PORT, GPIO_MODE_INPUT, GPIO_PUPD_NONE, BUTTON_PIN);
    gpio_mode_setup(USB_PORT, GPIO_MODE_AF, GPIO_PUPD_NONE, USB_PINS);
    gpio_set_af(USB_PORT, GPIO_AF10, USB_PINS);
    systick_set_clocksource(STK_CSR_CLKSOURCE_AHB);
    systick_set_reload(96000u - 1u);
    systick_interrupt_enable();
    systick_counter_enable();
    usb_serial_init();

    uint32_t last_blink = 0;
    bool was_open = false;
    char line[64];
    unsigned used = 0;
    bool overflow = false;
    for (;;) {
        usb_serial_poll();
        uint32_t now = ticks;
        bool open = usb_serial_open();
        if (open && !was_open) {
            usb_serial_write("devboard ready\r\nType help for commands.\r\n");
            used = 0; overflow = false;
        }
        was_open = open;
        if (blink && (uint32_t)(now - last_blink) >= 500u) {
            last_blink = now; led_set(!led_on);
        }
        if (button_update(&button, gpio_get(BUTTON_PORT, BUTTON_PIN) != 0, now)) {
            if (button.pressed) presses++;
            usb_serial_write(button.pressed ? "button pressed\r\n" : "button released\r\n");
        }
        char ch;
        while (usb_serial_getc(&ch)) {
            if (ch == '\r' || ch == '\n') {
                if (overflow) usb_serial_write("Command too long.\r\n");
                else if (used) { line[used] = '\0'; command(line); }
                used = 0; overflow = false;
            } else if (ch == '\b' || ch == 127) {
                if (used) used--;
            } else if (ch >= 32 && ch <= 126 && !overflow) {
                if (used < sizeof line - 1u) line[used++] = ch;
                else overflow = true;
            }
        }
    }
}

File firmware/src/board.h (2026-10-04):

#pragma once
#include <libopencm3/stm32/gpio.h>

#define LED_PORT GPIOC
#define LED_PIN GPIO13
#define BUTTON_PORT GPIOA
#define BUTTON_PIN GPIO0
#define USB_PORT GPIOA
#define USB_PINS (GPIO9 | GPIO11 | GPIO12)
#define BUTTON_DEBOUNCE_MS 25u

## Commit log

2026-09-14 init repo, devlog 01
    [devboard.kicad_pcb, devboard.kicad_sch]
2026-09-14 devlog 03
    [devboard.kicad_sch]
2026-09-15 pcb routing
    [devboard.kicad_pcb, devboard.kicad_sch]
2026-09-15 devlog 05
    [bom.csv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]
2026-09-18 devlog 07
    [bom.csv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]
2026-10-04 devlog 08
    [devboard-B_Cu.gbl, devboard-B_Mask.gbs, devboard-B_Paste.gbp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]
2026-10-10 added bom to readme
